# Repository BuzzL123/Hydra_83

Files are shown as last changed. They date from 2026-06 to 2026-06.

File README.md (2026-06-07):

# Hydra 83

> _One board. Two protocols. More to come._

  

---

## What Is It?

The **Hydra 83** is a custom 83-key mechanical keyboard that can switch between **USB HID** and **PS/2** via a hardware toggle. The name comes from two things:

- **83** — the total key count
- **Hydra** — the multi-headed creature of myth, representing the board's ability to switch between protocols. In PS/2 mode it's a standard PS/2 keyboard; in USB mode it's a USB keyboard that also accepts a PS/2 mouse on the PS/2 connector

The Hydra is intended to be a series. Future versions may add an integrated USB hub, additional protocol modes, or other switching features.

---

## Features

- **Dual-protocol keyboard output** — USB HID or PS/2 Scan Code Set 2, selected with a hardware toggle
- **PS/2 mouse input in USB mode** — plug a PS/2 mouse into the PS/2 connector while in USB mode; QMK's built-in PS/2 mouse driver reads it and forwards it to the host over USB
- **Full PS/2 keyboard implementation** — make/break codes, typematic repeat, E0-prefixed extended keys, F13–F24, multimedia, browser, and power keys
- **On-board BSS138 level shifters** — two BSS138 MOSFETs handle bidirectional 3.3 V ↔ 5 V translation on the PS/2 clock and data lines; no external components needed
- **OLED display** — SSD1306 128×32 connected via I2C
- **Rotary encoder** — Alps EC11E with push-to-click
- **USB-C connector** — with SRV05-4 ESD protection
- **Hardware mode switch** — debounced in firmware (50 ms)
- **QMK-based firmware** — fully remappable, built on QMK best practices, using QMK built-ins wherever possible

---

## How the Modes Work

### PS/2 Mode

The board operates as a standard PS/2 keyboard. Connect it to any PS/2 port — Scan Code Set 2, typematic repeat, full extended key support, all modifiers. The PS/2 clock and data lines are driven by the RP2040 through the BSS138 level shifters.

### USB Mode

The board enumerates as a USB HID keyboard. The PS/2 connector switches role: it becomes a **PS/2 mouse host**. Plug a PS/2 mouse in and QMK reads it and forwards mouse movement, buttons, and scroll to the host over USB alongside keyboard input — one USB-C cable, both devices.

---

## Layout

The Hydra 83 has 83 keys with an integrated numpad cluster, F1–F12 doubling as F13–F24, and a rotary encoder in the top-right corner.

---

## Repository Layout

```
├── Firmware/
│   ├── config.h
│   ├── halconf.h
│   ├── kb.c
│   ├── kb.h
│   ├── keyboard.json
│   ├── keymaps/
│   │   └── default/
│   │       └── keymap.c
│   ├── Makefile
│   ├── mcuconf.h
│   ├── ps2_keyboard.c
│   ├── ps2_keyboard.h
│   ├── ps2_scancodes.h
│   ├── readme.md
│   └── rules.mk
└── PCB/
    ├── gerbers/
    │   ├── bom.csv
    │   ├── designators.csv
    │   ├── Hydra_83_1.0.zip
    │   ├── netlist.ipc
    │   └── positions.csv
    ├── Hydra83_Schamatics.pdf
    ├── Hydra83__Assembly.pdf
    ├── ibom.html
    ├── kicad/
    │   ├── fabrication-toolkit-options.json
    │   ├── fp-lib-table
    │   ├── Hydra83.kicad_pcb
    │   ├── Hydra83.kicad_prl
    │   ├── Hydra83.kicad_pro
    │   ├── Hydra83.kicad_sch
    │   ├── Hydra83.net
    │   ├── kbplacer.log
    │   └── sch_data.json
    └── layout.png
```

PS/2 mouse host support uses QMK's built-in `PS2_MOUSE` feature, enabled in `rules.mk`.

---

## Hardware

### Key Components

|Ref|Part|Description|
|---|---|---|
|U3|RP2040|Microcontroller|
|U4|W25Q128JVS|128 Mbit external flash|
|U1|XC6206PxxxMR|3.3 V LDO regulator|
|U2, U6|SRV05-4|USB ESD protection|
|Q1, Q2|BSS138|PS/2 bidirectional level shifters|
|J2|USB-C receptacle|USB 2.0, 16-pin|
|P1|Mini-DIN 6-pin|PS/2 connector|
|J3|SSD1306|0.91" 128×32 OLED (I2C)|
|Y1|12 MHz crystal|RP2040 clock source|
|SW1|Tactile switch|BOOTSEL|
|SW2|Tactile switch|RESET|
|SW3|Toggle / jumper|Mode select (USB / PS/2)|
|RE1|Alps EC11E|Rotary encoder with switch|

### GPIO Pin Map

All 30 RP2040 GPIOs are used:

|GPIO|Signal|Notes|
|---|---|---|
|GP0|Row_0|Key matrix|
|GP1|Row_1||
|GP2|Row_2||
|GP3|Row_3||
|GP4|Row_4||
|GP5|Column_0||
|GP6|Column_1||
|GP7|Column_2||
|GP8|Column_3||
|GP9|Column_4||
|GP10|Column_5||
|GP11|Column_6||
|GP12|Column_7||
|GP13|Column_8||
|GP14|Column_9||
|GP15|Column_10||
|GP16|Column_11||
|GP17|Column_12||
|GP18|Column_13||
|GP19|Column_14||
|GP20|Column_15||
|GP21|Column_16||
|GP22|Column_17||
|GP23|Mode_Switch|HIGH = USB, LOW = PS/2|
|GP24|PS/2_Data|Through BSS138 level shifter|
|GP25|PS/2_Clock|Through BSS138 level shifter|
|GP26|I2C1_SDA|OLED (SSD1306)|
|GP27|I2C1_SCL|OLED (SSD1306)|
|GP28|Encoder_Up|Rotary encoder A|
|GP29|Encoder_Down|Rotary encoder B|

### PS/2 Connector Pinout (Mini-DIN 6)

|PS/2 Pin|Signal|Notes|
|---|---|---|
|1|Data|Through BSS138 to GP24|
|3|GND||
|4|VCC|VBUS (5 V)|
|5|Clock|Through BSS138 to GP25|

---

## PCB

KiCad source files, schematic PDF, PCB plot PDF, interactive HTML BOM (`ibom.html`), and JLCPCB fabrication files are all in the `PCB/` directory. The design is still being refined.

To view the interactive BOM, open `ibom.html` in any browser — it shows component placement on the board alongside the BOM table, useful for hand assembly.

---

## Firmware

### Prerequisites

- [QMK Firmware](https://docs.qmk.fm/#/newbs_getting_started) set up locally
- QMK CLI configured
- ARM GCC toolchain (installed by `qmk setup`)

### Build & Flash

```bash
# Copy the Firmware folder into your QMK keyboards directory
cd ~/qmk_firmware/keyboards
mkdir -p hydra83
cp -r /path/to/Hydra_83/Firmware hydra83/hydra83

# Compile
qmk compile -kb hydra83/hydra83 -km default

# Flash — double-tap reset on RP2040 to enter bootloader, then:
qmk flash -kb hydra83/hydra83 -km default
```

Or copy the pre-compiled `.uf2` from the [Releases](https://github.com/BuzzL123/Hydra_83/releases) page onto the `RPI-RP2` drive.

### Keymap Customization

Edit `Firmware/keymaps/default/keymap.c`. Full PS/2 Scan Code Set 2 support is already in the firmware — just change the layout array.

---

## Debugging

```bash
qmk console
```

```
================================
Mode switch: PS/2
================================
[PS2] PS/2 driver activated
[PS2] Key pressed: keycode=0x0004, scancode=0x1C
[PS2] Typematic repeat: keycode=0x0004, scancode=0x1C
[PS2] Key released: keycode=0x0004, scancode=0x1C
================================
Mode switch: USB
================================
[USB] USB driver restored
```

---

## PS/2 Protocol Details

The keyboard side operates in PS/2 **device** mode — the RP2040 acts _as_ a keyboard. Each byte is 11 bits (start, 8 data bits LSB-first, odd parity, stop) at ~10 kHz. The firmware handles:

- Make codes (key down) and break codes (`0xF0` + scancode, key up)
- E0-prefixed extended codes for arrows, navigation, multimedia, browser, and power keys
- Multi-byte sequences for Print Screen and Pause/Break
- Typematic repeat — 500 ms initial delay, ~30 repeats/second

In USB mode the same PS/2 lines (GP24/GP25) switch to input, and QMK's `PS2_MOUSE` driver reads standard PS/2 mouse packets and forwards them over USB HID.

---

## Roadmap

- [ ] Finalize PCB layout
- [ ] Software mode toggle via keypress (in addition to hardware switch)

---

## Contributing

Pull requests are welcome. Open an issue first for significant changes.

---

## License

GPL-2.0 — see LICENSE. Matches the QMK Firmware license for full compatibility.

---

## Author

**Betzalel J. Lewis** — [GitHub](https://github.com/BuzzL123)

_PS/2 device mode proof-of-concept: [QMK PS/2 USB Dual-Mode Keyboard](https://github.com/BuzzL123/QMK-PS2-USB-Dual-Mode-Keyboard)_

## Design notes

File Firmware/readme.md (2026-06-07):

# bjl/hydra/83

bjl/hydra/83

*A short description of the keyboard/project*

* Keyboard Maintainer: [BJL](https://github.com/BuzzL123)
* Hardware Supported: *The PCBs, controllers supported*
* Hardware Availability: *Links to where you can find this hardware*

Make example for this keyboard (after setting up your build environment):

    make bjl/hydra/83:default

Flashing example for this keyboard:

    make bjl/hydra/83:default:flash

See the [build environment setup](https://docs.qmk.fm/#/getting_started_build_tools) and the [make instructions](https://docs.qmk.fm/#/getting_started_make_guide) for more information. Brand new to QMK? Start with our [Complete Newbs Guide](https://docs.qmk.fm/#/newbs).

## Bootloader

Enter the bootloader in 3 ways:

* **Bootmagic reset**: Hold down the key at (0,0) in the matrix (usually the top left key or Escape) and plug in the keyboard
* **Physical reset button**: Briefly press the button on the back of the PCB - some may have pads you must short instead
* **Keycode in layout**: Press the key mapped to `QK_BOOT` if it is available

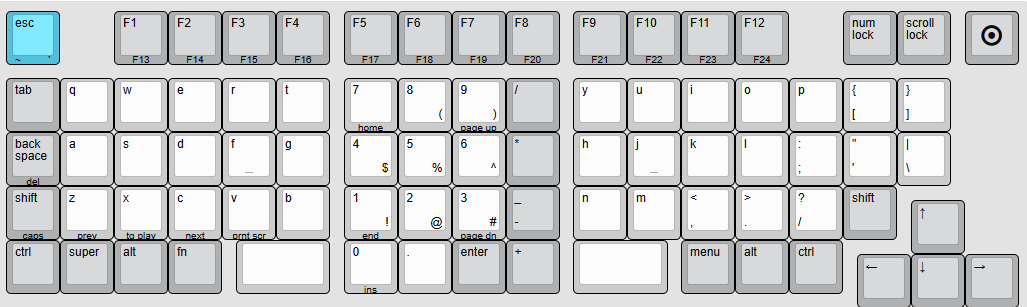
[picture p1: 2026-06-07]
PCB/layout.png

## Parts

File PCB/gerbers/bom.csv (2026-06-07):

Designator | Footprint | Quantity | Value | LCSC Part #
C1, C16, C2, C4, C5, C6, C7, C8, C9 | 402 | 9 | 100n | C60474
C10, C12, C13, C3 | 402 | 4 | 1u | C14445
C11 | 603 | 1 | 10u | C19702
C14, C15 | 402 | 2 | 22p | C106203
D1, D10, D11, D12, D13, D14, D15, D16, D17, D18, D19, D2, D20, D21, D22, D23, D24, D25, D26, D27, D28, D29, D3, D30, D31, D32, D33, D34, D35, D36, D37, D38, D39, D4, D40, D41, D42, D43, D44, D45, D46, D47, D48, D49, D5, D50, D51, D52, D53, D54, D55, D56, D57, D58, D59, D6, D60, D61, D62, D63, D64, D65, D66, D67, D68, D69, D7, D70, D71, D72, D73, D74, D75, D76, D77, D78, D79, D8, D80, D81, D82, D83, D9 | D_SOD-123 | 83 | D_Small | C83528
F1 | 1206 | 1 | Fuse_Small | C83798
J2 | USB_C_Receptacle_HRO_TYPE-C-31-M-12 | 1 | USB_C_Receptacle_USB2.0_16P | C2765186
J3 | SSD1306-0.91-OLED-4pin-128x32 | 1 | SSD1306
J4 | PinHeader_1x05_P2.54mm_Vertical | 1 | Debug
MX1, MX10, MX11, MX12, MX13, MX14, MX15, MX17, MX18, MX19, MX2, MX20, MX21, MX22, MX23, MX24, MX25, MX26, MX27, MX28, MX29, MX3, MX30, MX31, MX32, MX33, MX34, MX35, MX36, MX37, MX38, MX39, MX4, MX40, MX41, MX42, MX43, MX44, MX45, MX46, MX47, MX48, MX49, MX5, MX50, MX51, MX52, MX53, MX54, MX55, MX56, MX57, MX58, MX59, MX6, MX60, MX61, MX62, MX63, MX64, MX65, MX66, MX67, MX68, MX69, MX7, MX70, MX71, MX73, MX74, MX75, MX76, MX78, MX79, MX8, MX80, MX81, MX82, MX83, MX9 | SW_MX_1u | 80 | MX_SW_solder
MX16 | RotaryEncoder_Alps_EC11E-Switch_Vertical_H20mm | 1 | RotaryEncoder_Switch
MX72, MX77 | SW_MX_1.75u | 2 | MX_SW_solder
P1 | Connector_Mini-DIN_Female_6Pin_2rows | 1 | Mini-DIN_6pins | C7428703
Q1, Q2 | SOT-23 | 2 | BSS138 | C52895
R1, R10, R12, R13, R2, R7, R8, R9 | 402 | 8 | 5k1 | C105872
R11, R6 | 402 | 2 | 1k | C106235
R3, R4 | 402 | 2 | 27 | C138021
R5 | 402 | 1 | 5.1k | C105872
SW1 | SW_SPST_TL3342 | 1 | BOOTSEL | C318884
SW2 | SW_SPST_TL3342 | 1 | RST | C318884
SW3 | SW_Slide_SPDT_Angled_CK_OS102011MA1Q | 1 | Mode Sel | C221530
U1 | SOT-23-3 | 1 | XC6206PxxxMR | C5446
U2, U6 | SOT-23-6-routable | 2 | SRV05-4 | C151305
U3 | QFN-56-1EP_7x7mm_P0.4mm_EP3.2x3.2mm_ThermalVias | 1 | RP2040 | C2040
U4 | SOIC-8_5.3x5.3mm_P1.27mm | 1 | W25Q128JVS | C97521
Y1 | Crystal_SMD_3225-4Pin_3.2x2.5mm | 1 | 12MHz | C9002

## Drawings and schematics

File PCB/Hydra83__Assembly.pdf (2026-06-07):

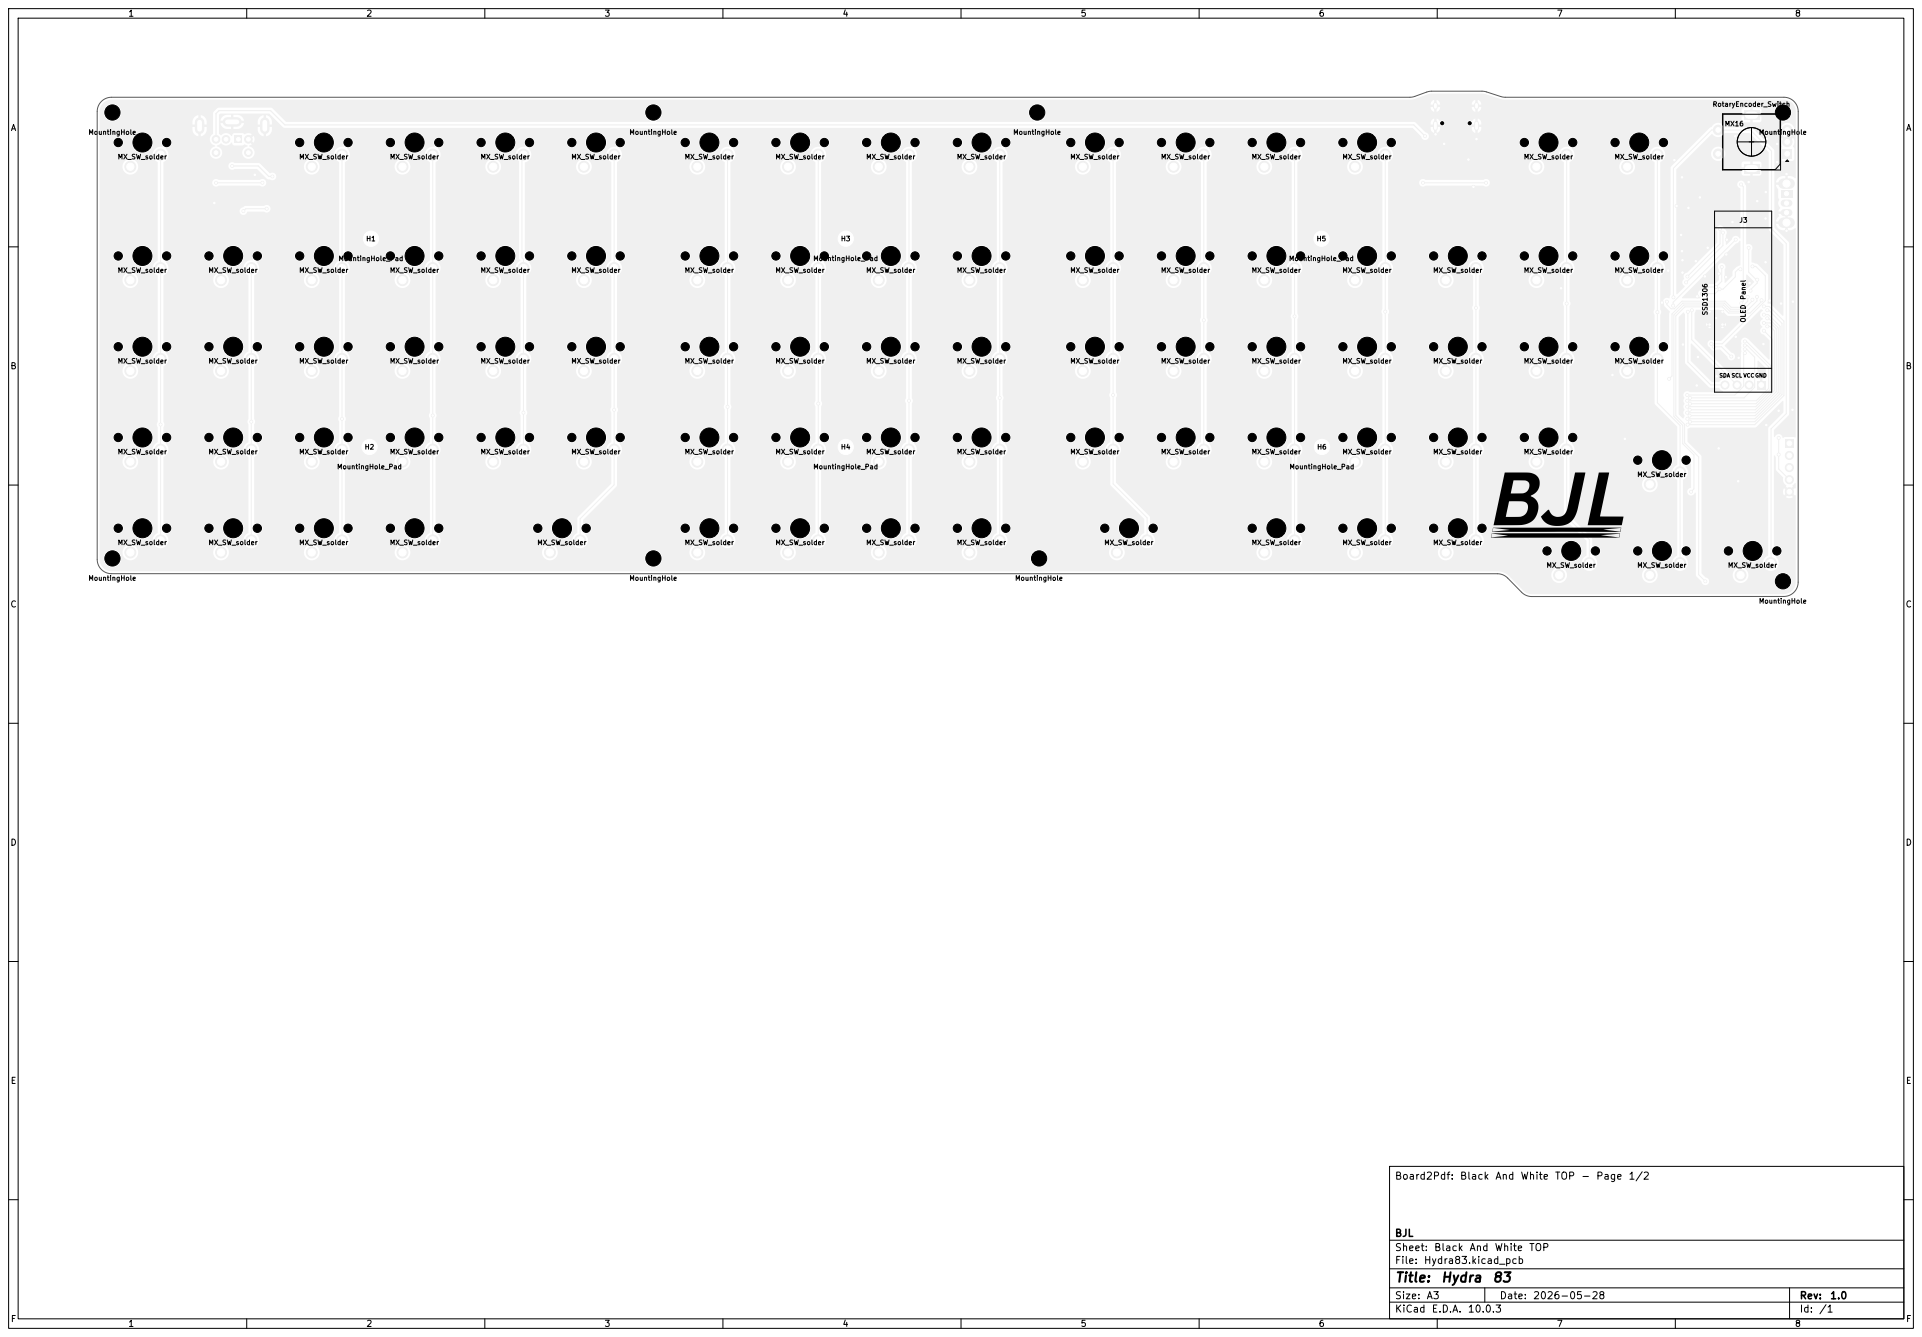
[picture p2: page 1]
SDA SCL OLED Panel VCC GND 1; F Date: 2026-05-28; Size: A3; Rev: 1.0; MountingHole H14; MX_SW_solder MX15 MX_SW_solder MX68; MX_SW_solder MX7 MX_SW_solder MX22; MX_SW_solder MX46; MX_SW_solder MX67 MX_SW_solder MX82 MX_SW_solder MX21 MX_SW_solder MX54; MX_SW_solder MX59 MX_SW_solder MX20; MX_SW_solder MX26 MX_SW_solder MX51; MX_SW_solder MX18 MX_SW_solder MX17; MX_SW_solder MX62 MX_SW_solder MX9; MX_SW_solder MX83 MountingHole H13 MX_SW_solder MX60; MX_SW_solder MX29 MX_SW_solder MX45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

Board2Pdf: Black And White TOP - Page 1/2

BJL
Sheet: Black And White TOP
File: Hydra83.kicad_pcb
Title: Hydra 83
KiCad E.D.A. 10.0.3

Date: 2026-05-28 | D29R8 | D72 D26 | D23 D57

R13 D69

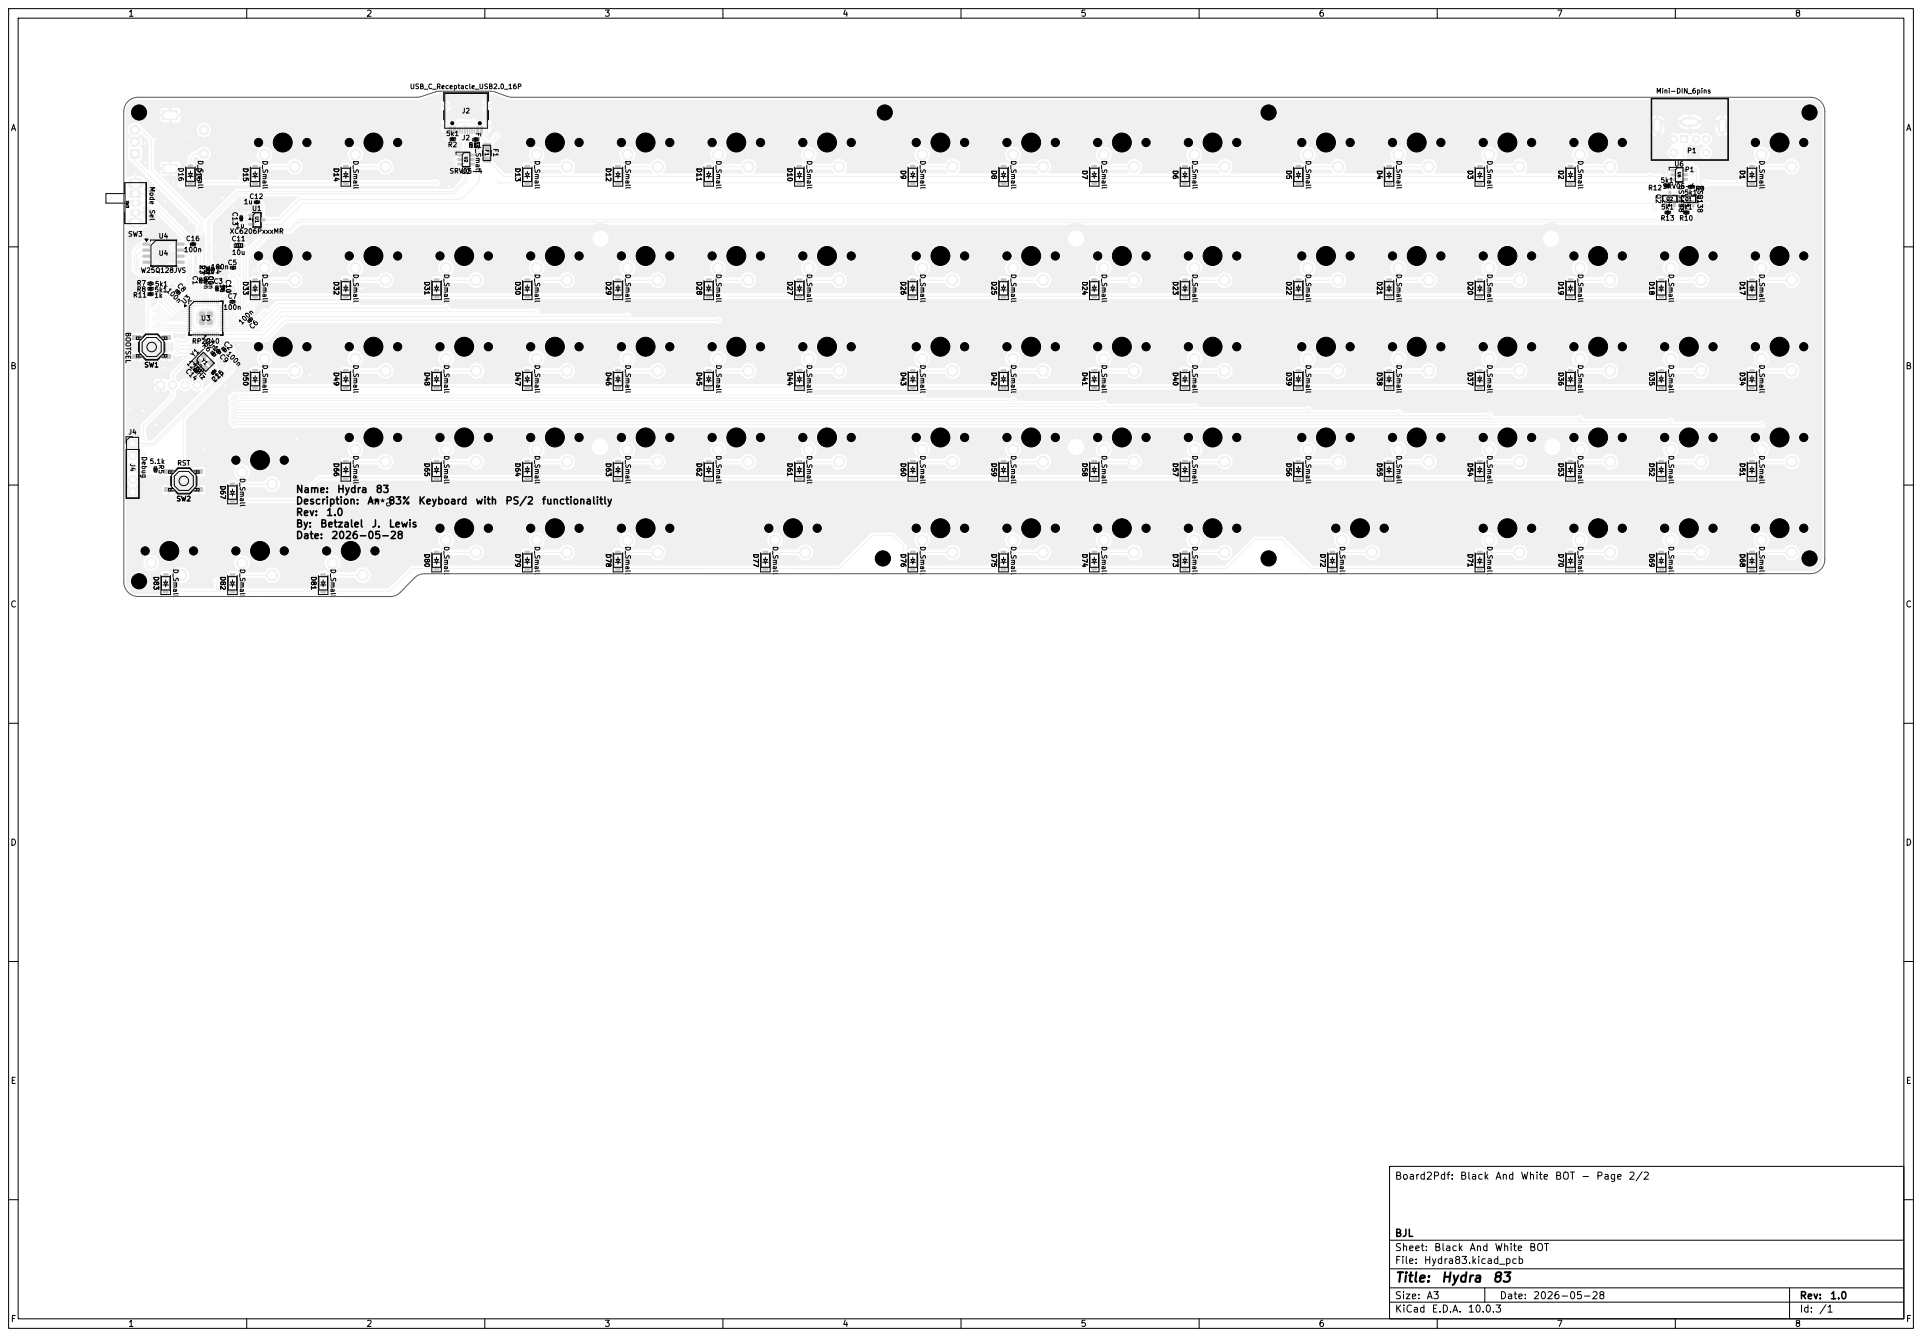
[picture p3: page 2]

Name: Hydra 83
Description: An 83% Keyboard with PS/2 functionalitly
Rev: 1.0
By: Betzalel J. Lewis

Board2Pdf: Black And White BOT - Page 2/2

BJL
Sheet: Black And White BOT
File: Hydra83.kicad_pcb
Title: Hydra 83
KiCad E.D.A. 10.0.3

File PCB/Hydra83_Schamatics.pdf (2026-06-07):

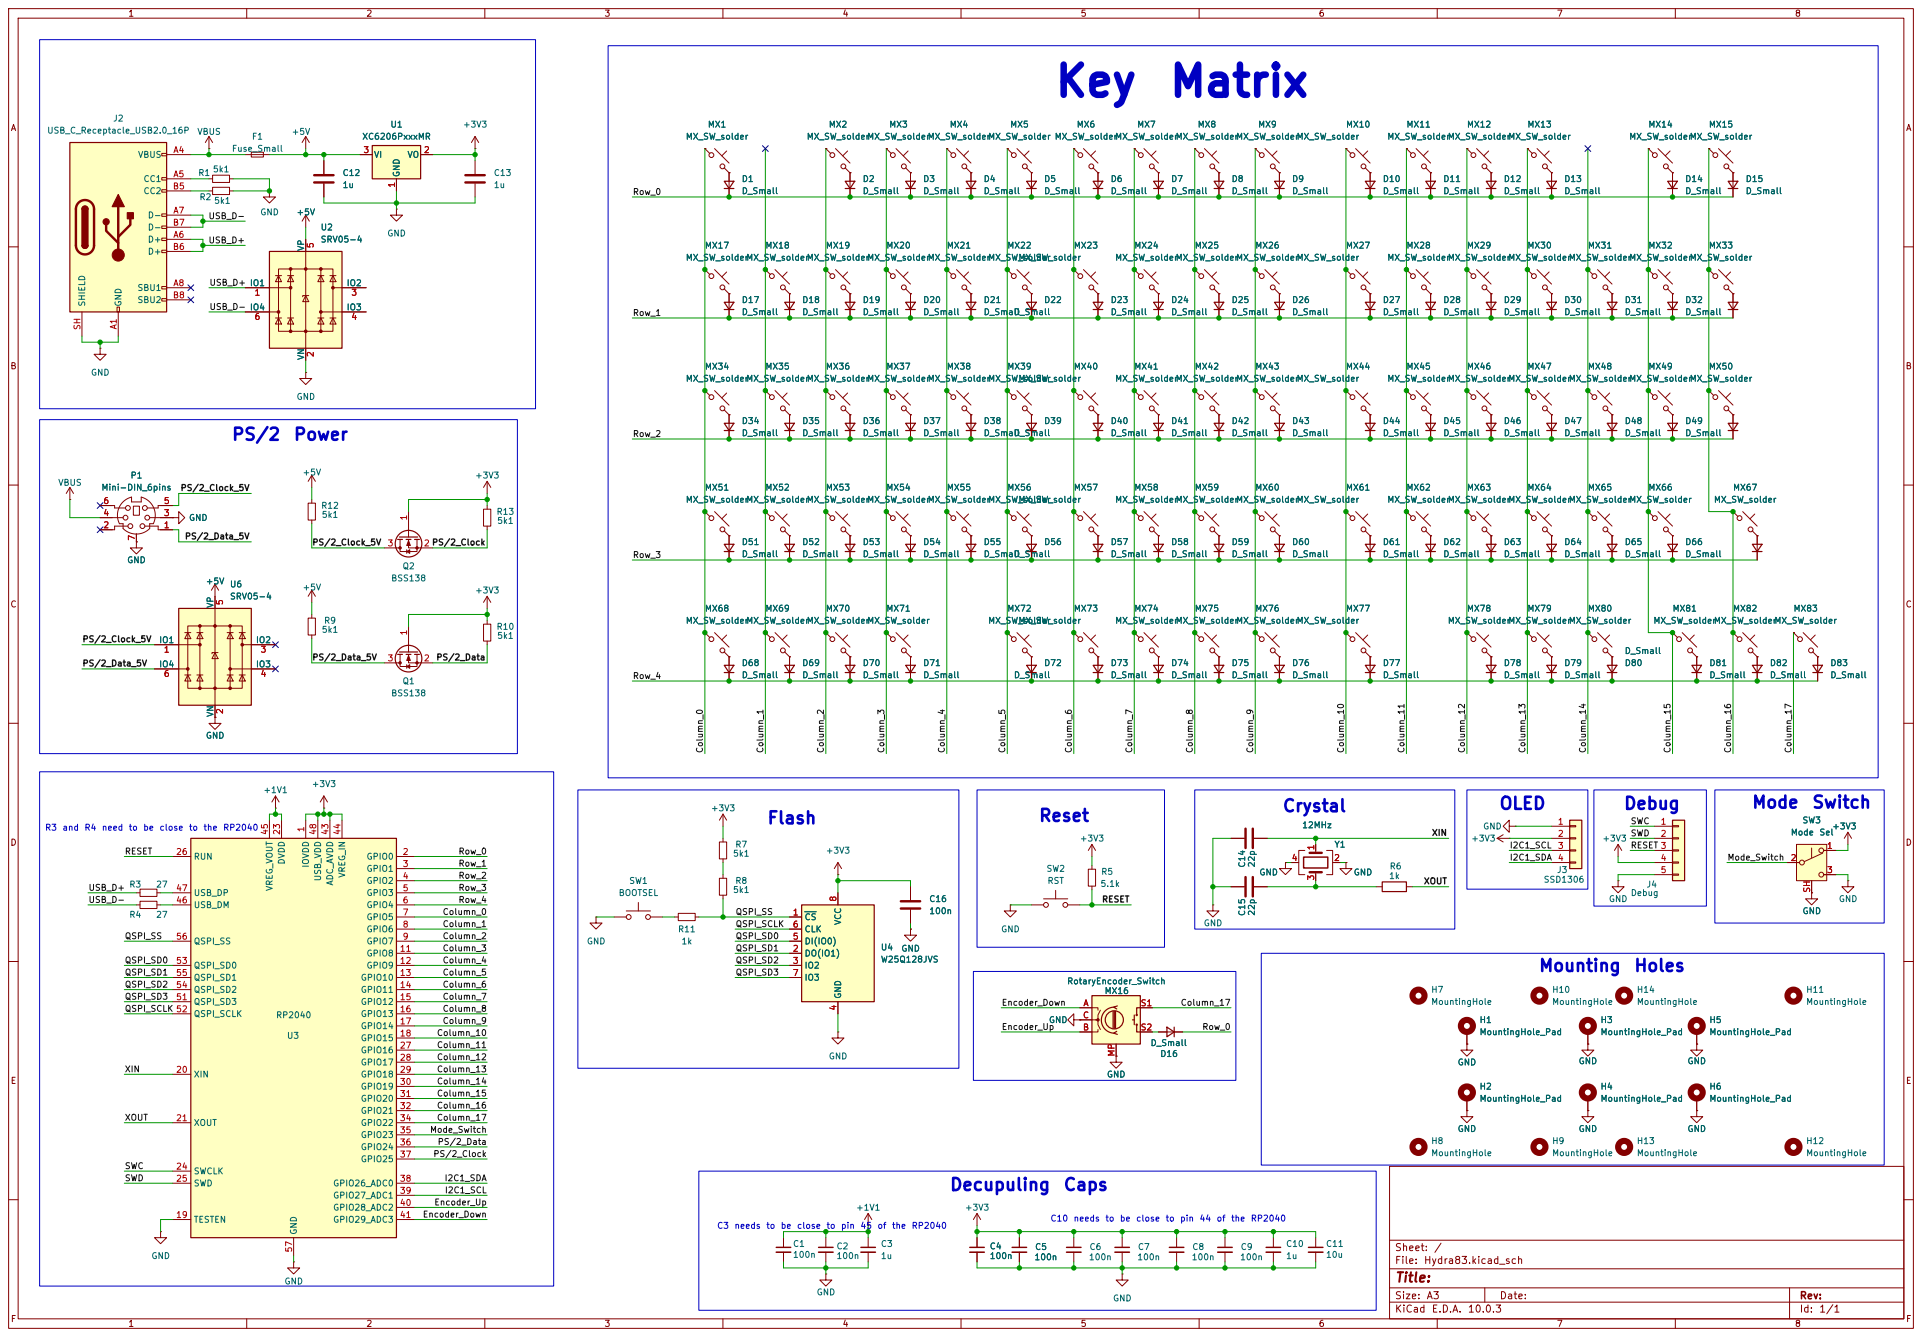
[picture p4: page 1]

C10 needs to be close to pin 44 of the RP2040 Key Matrix

Size: A3 | Rev: | F Date:
KiCad E.D.A. 10.0.3 | Id: 1/1

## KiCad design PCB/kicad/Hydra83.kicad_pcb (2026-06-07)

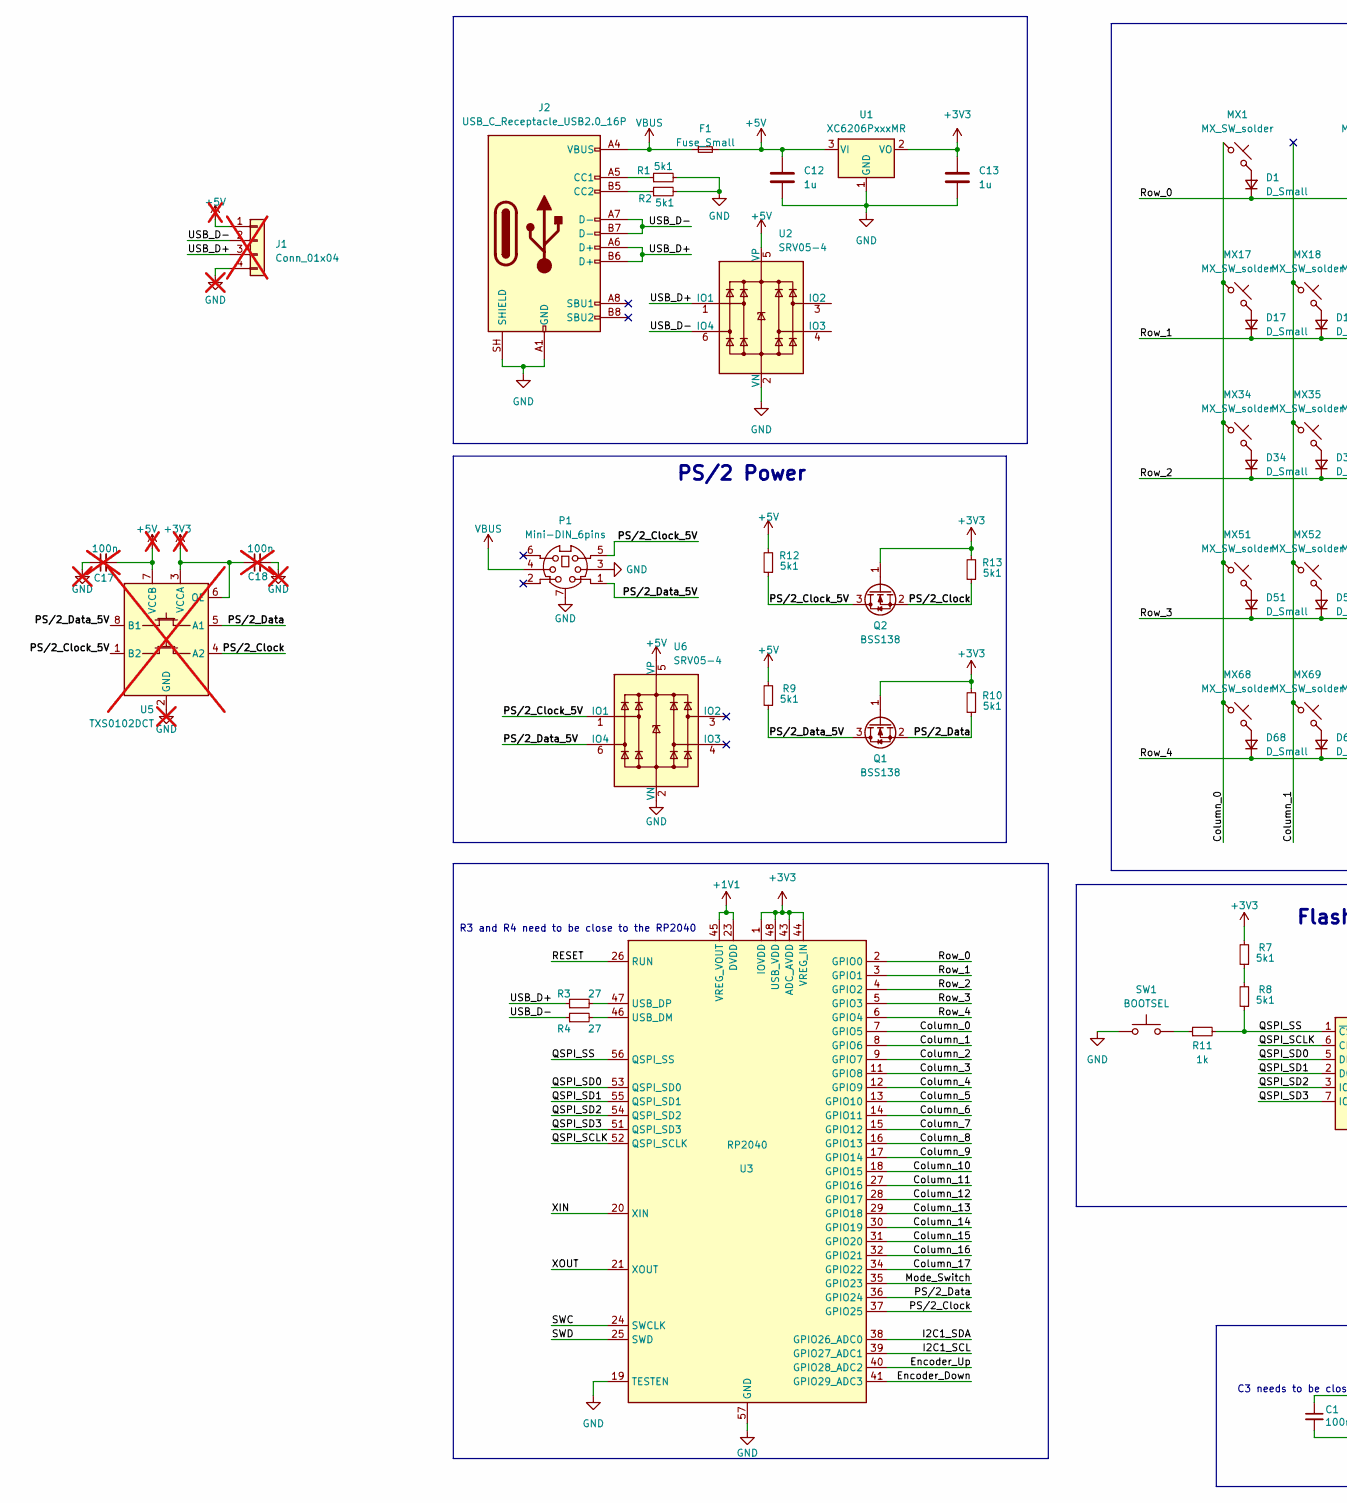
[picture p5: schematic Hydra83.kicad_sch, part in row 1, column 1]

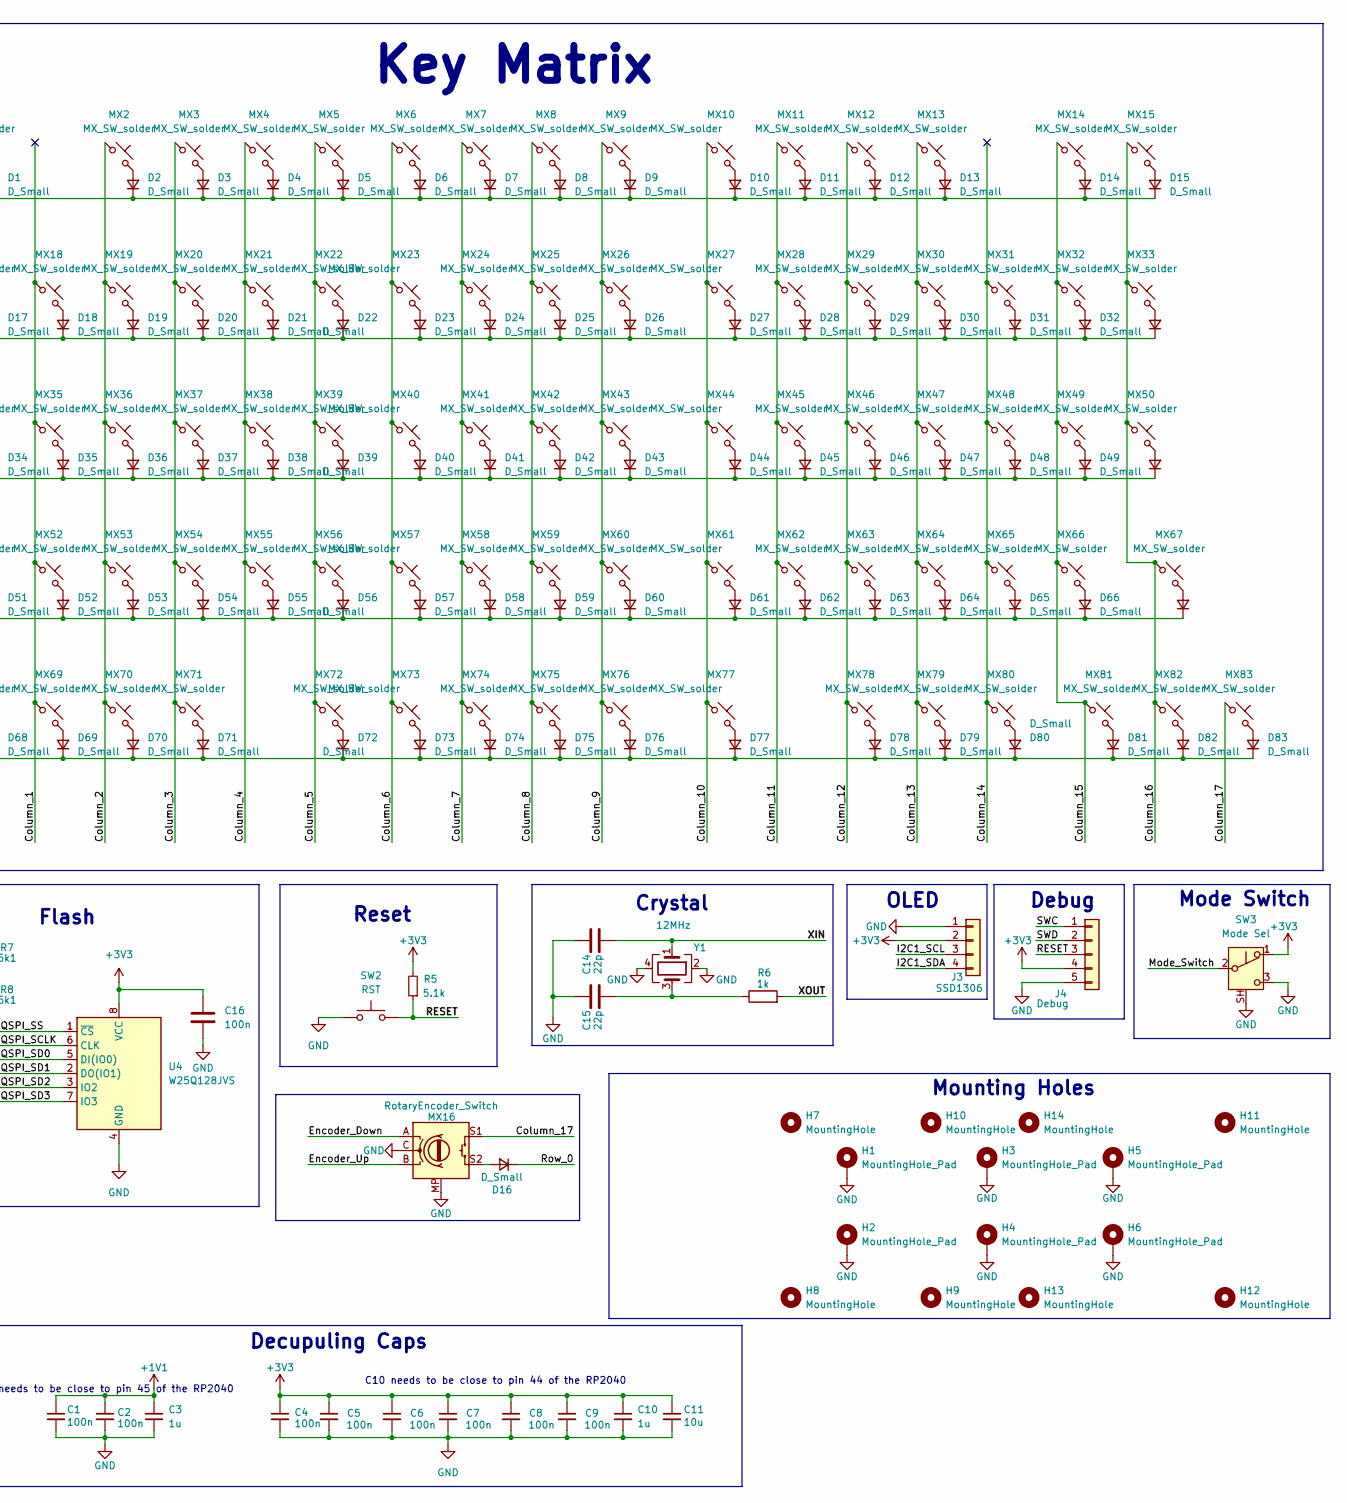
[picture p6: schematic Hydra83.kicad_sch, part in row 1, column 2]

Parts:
C1, C2, C4, C5, C6, C7, C8, C9, C16: 100n; C_0402_1005Metric
C3, C10, C12, C13: 1u; C_0402_1005Metric
C11: 10u; C_0603_1608Metric
C14, C15: 22p; C_0402_1005Metric
C17, C18: 100n; C_0402_1005Metric; not fitted
D1, D2, D3, D4, D5, D6, D7, D8, D9, D10, D11, D12, D13, D14, D15, D16, D17, D18, D19, D20, D21, D22, D23, D24, D25, D26, D27, D28, D29, D30, D31, D32, D33, D34, D35, D36, D37, D38, D39, D40, D41, D42, D43, D44, D45, D46, D47, D48, D49, D50, D51, D52, D53, D54, D55, D56, D57, D58, D59, D60, D61, D62, D63, D64, D65, D66, D67, D68, D69, D70, D71, D72, D73, D74, D75, D76, D77, D78, D79, D80, D81, D82, D83: D_Small; D_SOD-123
F1: Fuse_Small; Fuse_1206_3216Metric
H1, H2, H3, H4, H5, H6: MountingHole_Pad; MountingHole_3.2mm_M3_Pad
H7, H8, H9, H10, H11, H12, H13, H14: MountingHole; MountingHole_3.2mm_M3
J1: Conn_01x04; JST_SH_SM04B-SRSS-TB_1x04-1MP_P1.00mm_Horizontal; not fitted
J2: USB_C_Receptacle_USB2.0_16P; USB_C_Receptacle_HRO_TYPE-C-31-M-12
J3: SSD1306; SSD1306-0.91-OLED-4pin-128x32
J4: Debug; PinHeader_1x05_P2.54mm_Vertical
MX1, MX2, MX3, MX4, MX5, MX6, MX7, MX8, MX9, MX10, MX11, MX12, MX13, MX14, MX15, MX17, MX18, MX19, MX20, MX21, MX22, MX23, MX24, MX25, MX26, MX27, MX28, MX29, MX30, MX31, MX32, MX33, MX34, MX35, MX36, MX37, MX38, MX39, MX40, MX41, MX42, MX43, MX44, MX45, MX46, MX47, MX48, MX49, MX50, MX51, MX52, MX53, MX54, MX55, MX56, MX57, MX58, MX59, MX60, MX61, MX62, MX63, MX64, MX65, MX66, MX67, MX68, MX69, MX70, MX71, MX73, MX74, MX75, MX76, MX78, MX79, MX80, MX81, MX82, MX83: MX_SW_solder; SW_MX_1u
MX16: RotaryEncoder_Switch; RotaryEncoder_Alps_EC11E-Switch_Vertical_H20mm
MX72, MX77: MX_SW_solder; SW_MX_1.75u
P1: Mini-DIN_6pins; Connector_Mini-DIN_Female_6Pin_2rows
Q1, Q2: BSS138; SOT-23
R1, R2, R7, R8, R9, R10, R12, R13: 5k1; R_0402_1005Metric
R3, R4: 27; R_0402_1005Metric
R5: 5.1k; R_0402_1005Metric
R6, R11: 1k; R_0402_1005Metric
SW1: BOOTSEL; SW_SPST_TL3342
SW2: RST; SW_SPST_TL3342
SW3: Mode Sel; SW_Slide_SPDT_Angled_CK_OS102011MA1Q
U1: XC6206PxxxMR; SOT-23-3
U2, U6: SRV05-4; SOT-23-6-routable
U3: RP2040; QFN-56-1EP_7x7mm_P0.4mm_EP3.2x3.2mm_ThermalVias
U4: W25Q128JVS; SOIC-8_5.3x5.3mm_P1.27mm
U5: TXS0102DCT; SSOP-8_2.95x2.8mm_P0.65mm; not fitted
Y1: 12MHz; Crystal_SMD_3225-4Pin_3.2x2.5mm

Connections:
+1V1: C1.1, C2.1, C3.1, U3.23 (DVDD), U3.45 (VREG_VOUT), U3.50 (DVDD)
+3V3: C4.1, C5.1, C6.1, C7.1, C8.1, C9.1, C10.1, C11.1, C13.1, C16.1, C18.1, J3.2, J4.4, Q1.1 (G), Q2.1 (G), R5.2, R7.2, R10.2, R13.2, SW3.1 (A), U1.2 (VO), U3.1 (IOVDD), U3.10 (IOVDD), U3.22 (IOVDD), U3.33 (IOVDD), U3.42 (IOVDD), U3.43 (ADC_AVDD), U3.44 (VREG_IN), U3.48 (USB_VDD), U3.49 (IOVDD), U4.8 (VCC), U5.3 (VCCA), U5.6 (OE)
+5V: C12.1, C17.2, F1.2, J1.1, R9.2, R12.2, U1.3 (VI), U2.5 (VP), U5.7 (VCCB), U6.5 (VP)
/Column_0: MX1.1, MX17.1, MX34.1, MX51.1, MX68.1, U3.7 (GPIO5)
/Column_1: MX18.1, MX35.1, MX52.1, MX69.1, U3.8 (GPIO6)
/Column_2: MX2.1, MX19.1, MX36.1, MX53.1, MX70.1, U3.9 (GPIO7)
/Column_3: MX3.1, MX20.1, MX37.1, MX54.1, MX71.1, U3.11 (GPIO8)
/Column_4: MX4.1, MX21.1, MX38.1, MX55.1, U3.12 (GPIO9)
/Column_5: MX5.1, MX22.1, MX39.1, MX56.1, MX72.1, U3.13 (GPIO10)
/Column_6: MX6.1, MX23.1, MX40.1, MX57.1, MX73.1, U3.14 (GPIO11)
/Column_7: MX7.1, MX24.1, MX41.1, MX58.1, MX74.1, U3.15 (GPIO12)
/Column_8: MX8.1, MX25.1, MX42.1, MX59.1, MX75.1, U3.16 (GPIO13)
/Column_9: MX9.1, MX26.1, MX43.1, MX60.1, MX76.1, U3.17 (GPIO14)
/Column_10: MX10.1, MX27.1, MX44.1, MX61.1, MX77.1, U3.18 (GPIO15)
/Column_11: MX11.1, MX28.1, MX45.1, MX62.1, U3.27 (GPIO16)
/Column_12: MX12.1, MX29.1, MX46.1, MX63.1, MX78.1, U3.28 (GPIO17)
/Column_13: MX13.1, MX30.1, MX47.1, MX64.1, MX79.1, U3.29 (GPIO18)
/Column_14: MX31.1, MX48.1, MX65.1, MX80.1, U3.30 (GPIO19)
/Column_15: MX14.1, MX32.1, MX49.1, MX66.1, MX81.1, U3.31 (GPIO20)
/Column_16: MX15.1, MX33.1, MX50.1, MX67.1, MX82.1, U3.32 (GPIO21)
/Column_17: MX16.S1, MX83.1, U3.34 (GPIO22)
/Encoder_Down: MX16.A, U3.41 (GPIO29_ADC3)
/Encoder_Up: MX16.B, U3.40 (GPIO28_ADC2)
/I2C1_SCL: J3.3, U3.39 (GPIO27_ADC1)
/I2C1_SDA: J3.4, U3.38 (GPIO26_ADC0)
/Mode_Switch: SW3.2 (B), U3.35 (GPIO23)
/PS/2_Clock: Q2.2 (S), R13.1, U3.37 (GPIO25), U5.4 (A2)
/PS/2_Clock_5V: P1.5, Q2.3 (D), R12.1, U5.1 (B2), U6.1 (IO1)
/PS/2_Data: Q1.2 (S), R10.1, U3.36 (GPIO24), U5.5 (A1)
/PS/2_Data_5V: P1.1, Q1.3 (D), R9.1, U5.8 (B1), U6.6 (IO4)
/QSPI_SCLK: U3.52 (QSPI_SCLK), U4.6 (CLK)
/QSPI_SD0: U3.53 (QSPI_SD0), U4.5 (DI(IO0))
/QSPI_SD1: U3.55 (QSPI_SD1), U4.2 (DO(IO1))
/QSPI_SD2: U3.54 (QSPI_SD2), U4.3 (IO2)
/QSPI_SD3: U3.51 (QSPI_SD3), U4.7 (IO3)
/QSPI_SS: R8.1, R11.2, U3.56 (QSPI_SS), U4.1 (~CS)
/RESET: J4.3, R5.1, SW2.2, U3.26 (RUN)
/Row_0: D1.1 (K), D2.1 (K), D3.1 (K), D4.1 (K), D5.1 (K), D6.1 (K), D7.1 (K), D8.1 (K), D9.1 (K), D10.1 (K), D11.1 (K), D12.1 (K), D13.1 (K), D14.1 (K), D15.1 (K), D16.1 (K), U3.2 (GPIO0)
/Row_1: D17.1 (K), D18.1 (K), D19.1 (K), D20.1 (K), D21.1 (K), D22.1 (K), D23.1 (K), D24.1 (K), D25.1 (K), D26.1 (K), D27.1 (K), D28.1 (K), D29.1 (K), D30.1 (K), D31.1 (K), D32.1 (K), D33.1 (K), U3.3 (GPIO1)
/Row_2: D34.1 (K), D35.1 (K), D36.1 (K), D37.1 (K), D38.1 (K), D39.1 (K), D40.1 (K), D41.1 (K), D42.1 (K), D43.1 (K), D44.1 (K), D45.1 (K), D46.1 (K), D47.1 (K), D48.1 (K), D49.1 (K), D50.1 (K), U3.4 (GPIO2)
/Row_3: D51.1 (K), D52.1 (K), D53.1 (K), D54.1 (K), D55.1 (K), D56.1 (K), D57.1 (K), D58.1 (K), D59.1 (K), D60.1 (K), D61.1 (K), D62.1 (K), D63.1 (K), D64.1 (K), D65.1 (K), D66.1 (K), D67.1 (K), U3.5 (GPIO3)
/Row_4: D68.1 (K), D69.1 (K), D70.1 (K), D71.1 (K), D72.1 (K), D73.1 (K), D74.1 (K), D75.1 (K), D76.1 (K), D77.1 (K), D78.1 (K), D79.1 (K), D80.1 (K), D81.1 (K), D82.1 (K), D83.1 (K), U3.6 (GPIO4)
/SWC: J4.1, U3.24 (SWCLK)
/SWD: J4.2, U3.25 (SWD)
/USB_D+: J1.3, J2.A6 (D+), J2.B6 (D+), R3.1, U2.1 (IO1)
/USB_D-: J1.2, J2.A7 (D-), J2.B7 (D-), R4.1, U2.6 (IO4)
/XIN: C14.2, U3.20 (XIN), Y1.1
/XOUT: R6.2, U3.21 (XOUT)
GND: C1.2, C2.2, C3.2, C4.2, C5.2, C6.2, C7.2, C8.2, C9.2, C10.2, C11.2, C12.2, C13.2, C14.1, C15.1, C16.2, C17.1, C18.2, H1.1 (1_1), H2.1 (1_1), H3.1 (1_1), H4.1 (1_1), H5.1 (1_1), H6.1 (1_1), J1.4, J2.A1 (GND), J2.A12 (GND), J2.B1 (GND), J2.B12 (GND), J2.SH (SHIELD), J3.1, J4.5, MX16.C, MX16.MP, P1.3, P1.7 (Shell), R1.2, R2.2, SW1.1, SW2.1, SW3.3 (C), SW3.SH, U1.1 (GND), U2.2 (VN), U3.19 (TESTEN), U3.57 (GND), U4.4 (GND), U5.2 (GND), U6.2 (VN), Y1.2, Y1.4
unnamed: C15.2, R6.1, Y1.3
unnamed: D1.2 (A), MX1.2
unnamed: D2.2 (A), MX2.2
unnamed: D3.2 (A), MX3.2
unnamed: D4.2 (A), MX4.2
unnamed: D5.2 (A), MX5.2
unnamed: D6.2 (A), MX6.2
unnamed: D7.2 (A), MX7.2
unnamed: D8.2 (A), MX8.2
unnamed: D9.2 (A), MX9.2
unnamed: D10.2 (A), MX10.2
unnamed: D11.2 (A), MX11.2
unnamed: D12.2 (A), MX12.2
unnamed: D13.2 (A), MX13.2
unnamed: D14.2 (A), MX14.2
unnamed: D15.2 (A), MX15.2
unnamed: D16.2 (A), MX16.S2
unnamed: D17.2 (A), MX17.2
unnamed: D18.2 (A), MX18.2
unnamed: D19.2 (A), MX19.2
unnamed: D20.2 (A), MX20.2
unnamed: D21.2 (A), MX21.2
unnamed: D22.2 (A), MX22.2
unnamed: D23.2 (A), MX23.2
unnamed: D24.2 (A), MX24.2
unnamed: D25.2 (A), MX25.2
unnamed: D26.2 (A), MX26.2
unnamed: D27.2 (A), MX27.2
unnamed: D28.2 (A), MX28.2
unnamed: D29.2 (A), MX29.2
unnamed: D30.2 (A), MX30.2
unnamed: D31.2 (A), MX31.2
unnamed: D32.2 (A), MX32.2
unnamed: D33.2 (A), MX33.2
unnamed: D34.2 (A), MX34.2
unnamed: D35.2 (A), MX35.2
unnamed: D36.2 (A), MX36.2
unnamed: D37.2 (A), MX37.2
unnamed: D38.2 (A), MX38.2
unnamed: D39.2 (A), MX39.2
unnamed: D40.2 (A), MX40.2
unnamed: D41.2 (A), MX41.2
unnamed: D42.2 (A), MX42.2
unnamed: D43.2 (A), MX43.2
unnamed: D44.2 (A), MX44.2
unnamed: D45.2 (A), MX45.2
unnamed: D46.2 (A), MX46.2
unnamed: D47.2 (A), MX47.2
unnamed: D48.2 (A), MX48.2
unnamed: D49.2 (A), MX49.2
unnamed: D50.2 (A), MX50.2
unnamed: D51.2 (A), MX51.2
unnamed: D52.2 (A), MX52.2
unnamed: D53.2 (A), MX53.2
unnamed: D54.2 (A), MX54.2
unnamed: D55.2 (A), MX55.2
unnamed: D56.2 (A), MX56.2
unnamed: D57.2 (A), MX57.2
unnamed: D58.2 (A), MX58.2
unnamed: D59.2 (A), MX59.2
unnamed: D60.2 (A), MX60.2
unnamed: D61.2 (A), MX61.2
unnamed: D62.2 (A), MX62.2
unnamed: D63.2 (A), MX63.2
unnamed: D64.2 (A), MX64.2
unnamed: D65.2 (A), MX65.2
unnamed: D66.2 (A), MX66.2
unnamed: D67.2 (A), MX67.2
unnamed: D68.2 (A), MX68.2
unnamed: D69.2 (A), MX69.2
unnamed: D70.2 (A), MX70.2
unnamed: D71.2 (A), MX71.2
unnamed: D72.2 (A), MX72.2
unnamed: D73.2 (A), MX73.2
unnamed: D74.2 (A), MX74.2
unnamed: D75.2 (A), MX75.2
unnamed: D76.2 (A), MX76.2
unnamed: D77.2 (A), MX77.2
unnamed: D78.2 (A), MX78.2
unnamed: D79.2 (A), MX79.2
unnamed: D80.2 (A), MX80.2
unnamed: D81.2 (A), MX81.2
unnamed: D82.2 (A), MX82.2
unnamed: D83.2 (A), MX83.2
unnamed: J2.A5 (CC1), R1.1
unnamed: J2.B5 (CC2), R2.1
unnamed: R7.1, R8.2
unnamed: R11.1, SW1.2
unnamed: R4.2, U3.46 (USB_DM)
unnamed: R3.2, U3.47 (USB_DP)
VBUS: F1.1, J2.A4 (VBUS), J2.A9 (VBUS), J2.B4 (VBUS), J2.B9 (VBUS), P1.4

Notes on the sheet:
Debug
OLED
Decupuling Caps
Crystal
R3 and R4 need to be close to the RP2040
Mode Switch
C3 needs to be close to pin 45 of the RP2040
Flash
Reset
PS/2 Power
C10 needs to be close to pin 44 of the RP2040
Mounting Holes
Key Matrix

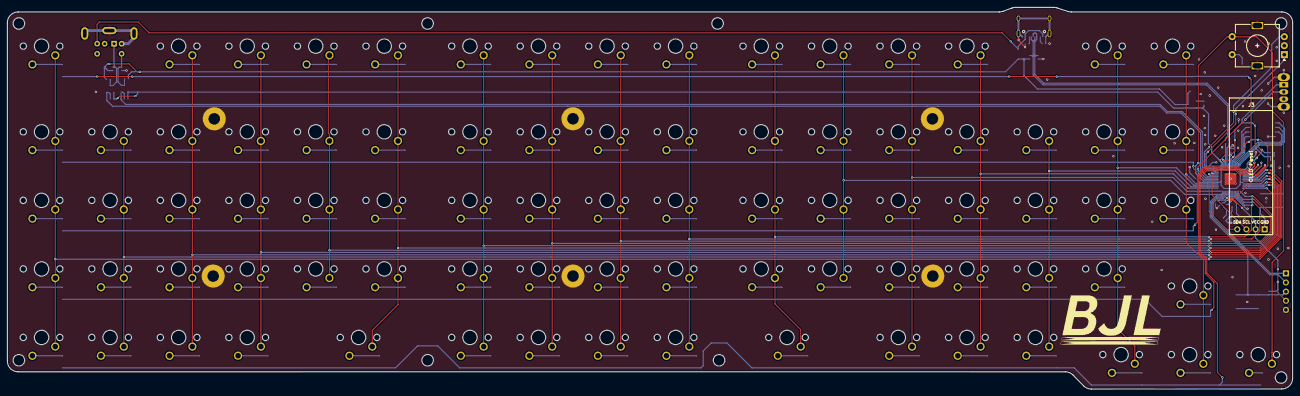
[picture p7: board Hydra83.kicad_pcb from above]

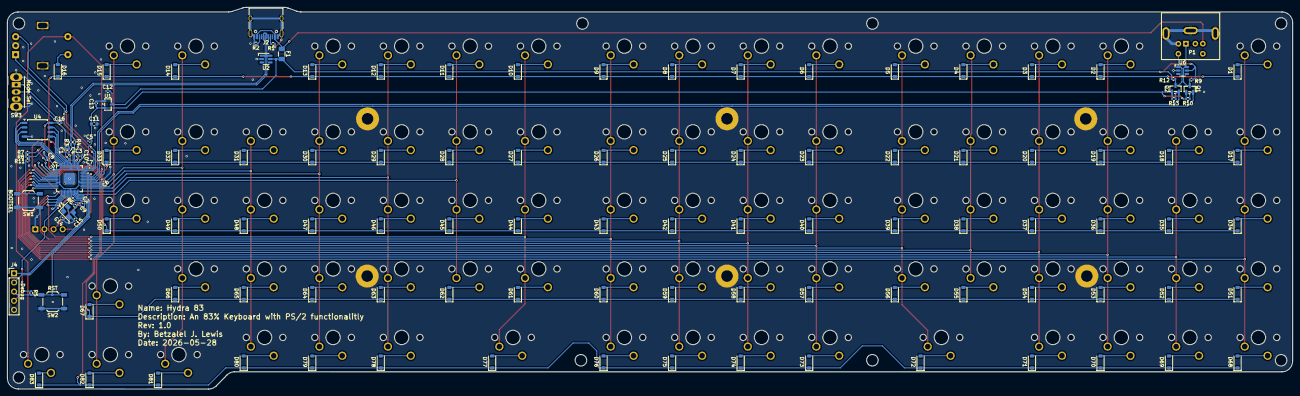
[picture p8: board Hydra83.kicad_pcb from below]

Board: 2 copper layers, 357.2 x 106.1 mm, 225 parts (127 on the bottom side), 140 nets.

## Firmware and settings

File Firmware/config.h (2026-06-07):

#pragma once

#define RP2040_BOOTLOADER_DOUBLE_TAP_RESET
#define RP2040_BOOTLOADER_DOUBLE_TAP_RESET_TIMEOUT 200U
#define RP2040_BOOTLOADER_DOUBLE_TAP_RESET_LED GP25

#define NO_USB_STARTUP_CHECK true

/* Shared PS/2 Port Pins */
#define PS2_CLOCK_PIN   GP25
#define PS2_DATA_PIN    GP24
#define MODE_SWITCH_PIN GP23

/* OLED */
#ifdef OLED_ENABLE
#define I2C1_SDA_PIN        GP26
#define I2C1_SCL_PIN        GP27
#define I2C_DRIVER          I2CD1
#define OLED_DISPLAY_128X32
#define OLED_BRIGHTNESS     128
#endif

/* GPIO Compatibility Shims for Modern QMK API */
#define setPinInput(pin)         gpio_set_pin_input(pin)
#define setPinInputHigh(pin)     gpio_set_pin_input_high(pin)
#define setPinInputLow(pin)      gpio_set_pin_input_low(pin)
#define setPinOutput(pin)        gpio_set_pin_output(pin)
#define writePinHigh(pin)        gpio_write_pin_high(pin)
#define writePinLow(pin)         gpio_write_pin_low(pin)
#define readPin(pin)             gpio_read_pin(pin)
#define togglePin(pin)           gpio_toggle_pin(pin)
